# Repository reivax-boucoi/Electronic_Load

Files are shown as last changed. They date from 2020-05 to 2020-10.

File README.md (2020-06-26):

# Electronic Load

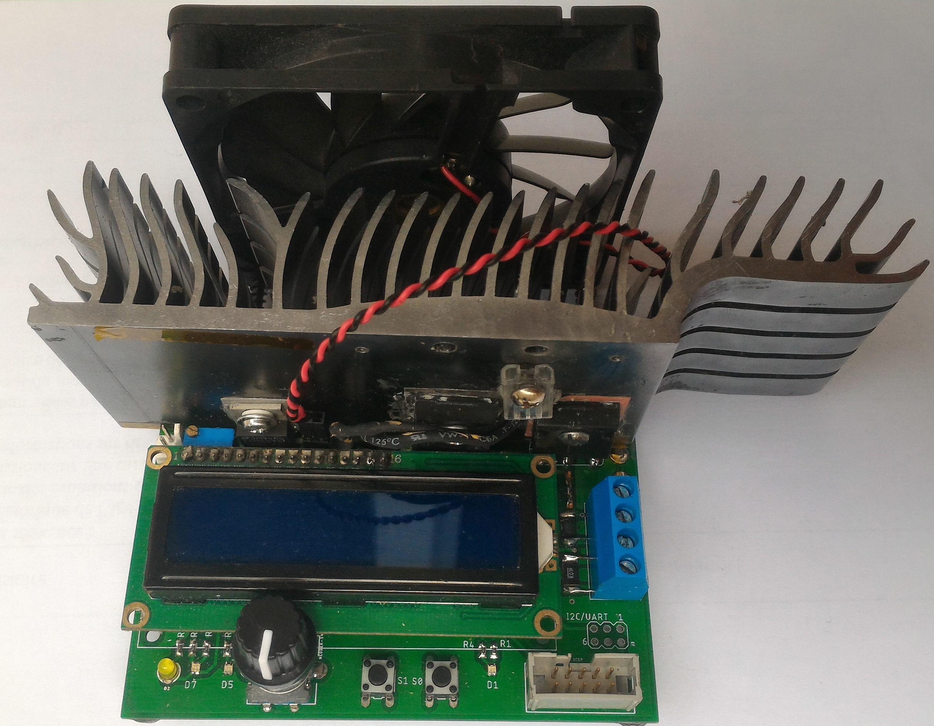
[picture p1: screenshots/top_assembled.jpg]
Image of top assembled


This repository hosts my work in developping a custom electronic load from scratch. 
For more information on what an electronic load does and what it can be used for, see [this](https://www.mouser.com/pdfdocs/DC_Electronic_Load_Application_Note.pdf). 

Specifically, this load targets DC-DC converters testing, as it includes input and output power monitoring.

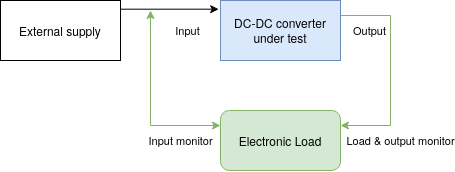
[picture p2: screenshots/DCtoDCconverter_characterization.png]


I you have any question on this repository, feel free to contact the owner at (reivax[dot]boucoi[at]laposte[dot]net).

Featured on [Hackaday](https://hackaday.com/2020/06/06/a-diy-electronic-load-with-a-twist/) and [Electronics-Lab](https://www.electronics-lab.com/diy-electronic-load-dc-dc-converter-characterization/)!

---
---

### Features

* Constant Current, Power and Resistance modes
* Battery capacity logging with adjustable cutoff voltage
* Input and output power logging : instant efficiency reading for DC-DC converters
* Rotary encoder driven interface
* Dedicated Load ON/OFF button
* Intuitive LCD menu system with editable values
* 12bit current, voltage and power measurements 
* 30W continuous sinking capability, 250W peak
* Temperature controlled fan with auto shutdown.
* Adjustable acquistion rate
* 115200 bauds serial communication through USB with a PC (non-isolated !)

### Specifications
> Enough talk, give us the specs, son !

Altough the device has not been fully qualified through systematic testing, here are the basic specs you can expect. 
* Input voltage range : 0 - 100V DC maximum, 2-80V DC regulating
* Supply voltage range : 0 - 16V maximum, 12V nominal 
* Device current consumption : 50mA nominal (0.6W)
* Load current range : 5mA - 5.25A, in 8mA steps
* Current regulation : 5% +/- 8mA typical @ 8kHz bandwidth
* Transient response : rise time < 20µs/A, overshoot < 2%
* Constant Power/Resistance regulation bandwidth : 10Hz

---
---

## Schematic and Layout
The heart of the system is an Atmel ATmega328P AVR microcontroller with 32kB of Flash and 2k of RAM running at a whopping 16MHz. It interfaces an I2C 12bit DAC (the MCP47FEB21A1) and the LTC2992 dual power monitor chip.

The USB serial interface uses the MCP2221A bridge. The display is a classic 16x2 LCD.

On the analog part, 10mΩ  and 0.2Ω shunt resistors are used, coupled with two W9NK90Z N-ch power MOSFETS. The heatsink was salvaged from an old graphics card. Attached are a 10k NTC and a generic fan (12v @ 200mA, 80mm). Current regulation is achieved through the help of a MCP6H02 opamp, and a carefully designed feedback network which guarantees the specified rise time with little to no overshoot.

The layout was done using the Eagle software (v9.5.2). Gerbers, Eagle project files, top and bottom views are available on the `pcb` folder. PCBs were printed using JLCPCB service.
The schematic is available in a pdf and Eagle `.sch` format as well. A Bill of Materials (BOM) is also available, in plain text and html format, on the `pcb` folder.

Several user-definable bi-color status LEDs are included, such as Load ON/OFF, TX & RX, acquisition blink, as well as a power LED.

An expansion/debug port is provided, with +5V, ground, I2C and UART available.

There are several issues regarding the layout of the PCB, as it is a first version. Improper Kelvin connections to the current sense resistors, or wrong hole size for the power input connector by example. The heatsink originally used is salvaged from old equipement and the footprint may not be relevant to anyone else. Space for rubber feet placement should be included. Also, the LCD is too close to the heatsink, which is impractical during assembly (especially accessing the fan and temp sensor connector).

---
---

## Firmware
The firmware for this device is currently in revision 1.3. It is written for a barebone ATmega328p Atmel microcontroller.

```20014 bytes (65%) of program storage space. Maximum is 30720 bytes.```

```1586 bytes (77%) of dynamic memory, 462 bytes left. Maximum is 2048 bytes.```

As you can see it's not the lightest firmware, mostly due to the use of the `Wire` and `LCD` librairies from Arduino, which are bulky. However, there is still enough room for future improvements. Just keep in mind if you want to improve the project to leave space for local variables allocation.

---

### Programming
An ISP port is provided on the board, making reflashing easy. All you need is an AVR-compatible programmer with the standard 10 pins ICSP header. I used the very good (and very cheap!) [Usbasp](https://www.fischl.de/usbasp/) during developpement. Avrdude can be used to download the pre-compiled binary `main.hex`, or you can compile the project yourself first.
`Avr Fuses settings :(E:FD, H:DE, L:FF)`

To program the chip, execute : `avrdude -p m328p -c usbasp -P usb -U flash:w:firmware/main.hex`

---

### Software structure

* Display related stuff : `Screen.cpp`, `Menu.cpp`
* LTC2992 power monitoring stuff : `PM.cpp`
* DC Load stuff : `Load.cpp`
* Generic io interfacing : `Utils.cpp`, `SimpleRotary.cpp`, `Wire.cpp`, `LCD.cpp`
* Serial command parsing : `SerialCommand.cpp`
* Serial interface : `Interface.cpp`
* Control loop and display update : `main.cpp`

---

### Usage
First apply power to the device through USB (for limited load capacity) or, better, 12V DC on the input power jack (beware of polarity).

The welcome screen pops up with the following menus : 

<img src="screenshots/mainmenu.jpg" alt="Image of mainmenu" width="200" text-align: center/>

* Load allows you to set the load parameters and mode (CC/CP/CR)
* Battery enters the battery capacity mode
* Meter measures input power
* Settings is self explanatory

Turn the rotary encoder to cycle through the menus and screens, and push to enter. At any time use the back button (to the right of the encoder) to get back to the previous menu or exit editing mode. 

Editing a value starts by selecting the value to edit. Press enter on a screen, you should get a flashing square in front of a value. Turn the knob until the desired value is selected. Press enter to edit. The leftmost digit is selected. To change the edited digit, press enter once again. Press back to validate. 

**You will have to restart the load in order for the changes to take effect.** This is done to prevent happy little accidents. To start and stop the load, press the rightmost button. The rightmost blue LED should light up. If the rightmost LED turns red, a fault occured. Faults can happen if :
* The heatsink temperature exceeds the hard temperature stop defined in `Load.h`
* The load fails to regulate. This will mostly be caused by the DUT hiccuping (or sharp V/I curve), or insufficent power to the Electronic Load.

The load menu has 4 screens : 

<img src="screenshots/screen_cc.jpg" alt="Image of ccscreen" width="200" text-align: center/><img src="screenshots/screen_cp.jpg" alt="Image of cpscreen" width="200" text-align: center/><img src="screenshots/screen_cr.jpg" alt="Image of crscreen" width="200" text-align: center/><img src="screenshots/screen_eff.jpg" alt="Image of effscreen" width="200" text-align: center/>

The last screen shows the power lost in the DUT (Pr), the efficiency, the input and output voltages of the converter.

The load mode (CC/CP/CR) is determined by the screen displayed when the load is started. If the screen is not one of the CC/CP/CR screens, is starts in the previously used mode.

Here is what the Battery screen looks like :

<img src="screenshots/screen_batt.jpg" alt="Image of battscreen" width="200" text-align: center/>

Set the constant discharge current I and the cutoff voltage Vc before starting the load with the rightmost button. Accumulated capacity in Wh and Ah are displayed. The load will automatically shut off when the input voltage is below the cutoff voltage, and output the capacity values to the serial port. The total capacity will remain displayed until the load is restarted in this mode.

The meter screen shows the input measurements :

<img src="screenshots/screen_meter.jpg" alt="Image of meterscreen" width="200" text-align: center/>

The settings screen alows to modify various parameters : 

<img src="screenshots/screen_settings.jpg" alt="Image of settingsscreen" width="200" text-align: center/>

It monitors the supply voltage and you can change the threshold temperature for the fan, as well as the refresh rate of the screen. Note that the load has a hard temperature stop defined in `Load.h`, and a maximum refresh rate of approx 10Hz.

---

### Serial interface

Several remote operations are available currently, for the load to report data to an external PC. The serial interface provided though USB (115200 bauds) defines the following commands :
- `get [x]` : returns current load data in the format shown below. Once the load is started (manually or with a command), it will take x samples at the acquisition time currently defined and then shut the load down.
- `sweep b e s` : sweeps the current settable value from `b` to `e` in `s` steps. Therefore, current, power or equivalent resistance can be characterized. THis mode is especially useful for efficiency over load characterization. The load is automatically enabled and disabled. Samples are taken after a stabilization time equal to the acquisition time. If the load cannot maintain regulation during the sweep, it will be aborted.
TODO add other commands

Parameters beween brackets are optional.

Example format of response from the load :
TODO here

---
---

## Improvements

- [x] Design a mechanical mount for the fan / stabilize the board
- [x] Re-think the menu system to be more modular / lower size
- [x] Add logging capability with serial interface
- [x] Add current sweep programming for DC-DC converters automatic characterization (with di/dv auto resolution)
* Cleanup and enhance the serial interface (add change mode command, load on/off) 
* Provide python example for graphing live data
* Fix the minimum current issue (currently min is 5mA)
* Fix the 4 terminal Kelvin connection on the 10mΩ current sense resistors in the PCB layout
* Design a usb isolator companion board or add SD card logging addon on i2c bus.
* Design 4.5V->12V boost addon to allow full operation from usb power (check usb power requirements before !)
* Better code commenting
* Save last used confguration on EEPROM for next power-up (is this really needed ?).
* ...

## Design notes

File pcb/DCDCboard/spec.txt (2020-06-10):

Input :

Voltage = 4.8V			USB (before diode so to not backfeed)

=> implies to step down for system power with linear reg (inefficient)

Current = 

Output :

Voltage = 12V nom +-.3V ripple max
Current = ~0.3A 		system + fan(beware of turn on current)

Calculation :

Pout = 12*.3 = 3.6W
Estimated efficiency = 70%
Pin = 3.6/.7 = 5.2W		Is this doable with USB ? What params for MCP2221A to request current ?
Current = 5.2/4.8 = 1.07A	Check with MC34063 max Isw

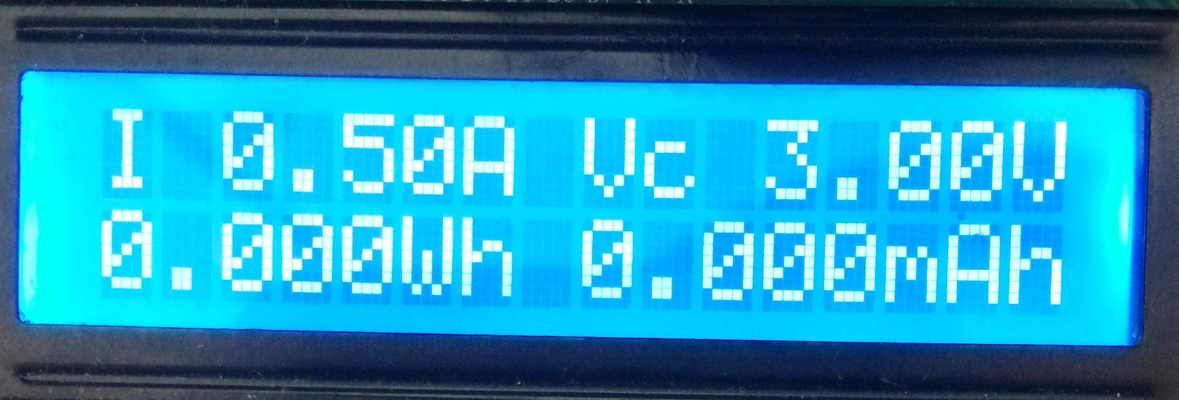
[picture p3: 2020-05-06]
screenshots/screen_batt.jpg

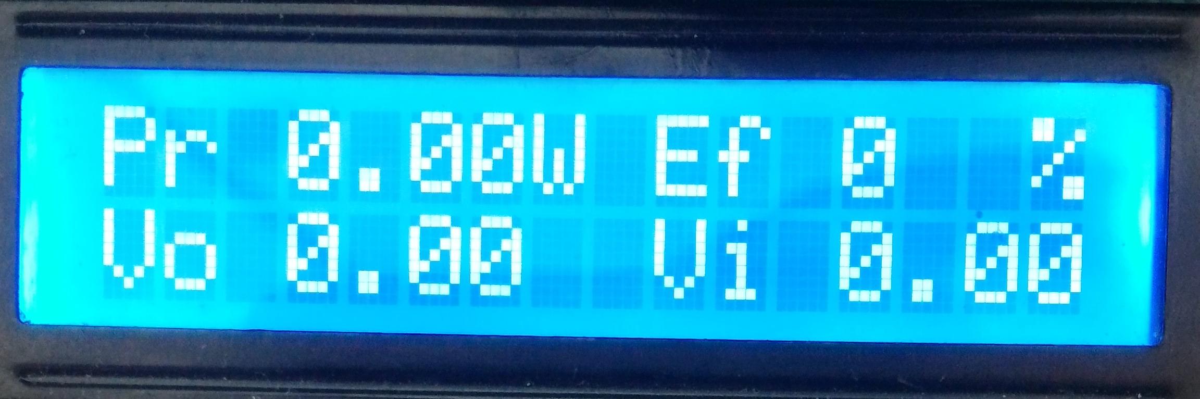
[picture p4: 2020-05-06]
screenshots/screen_eff.jpg

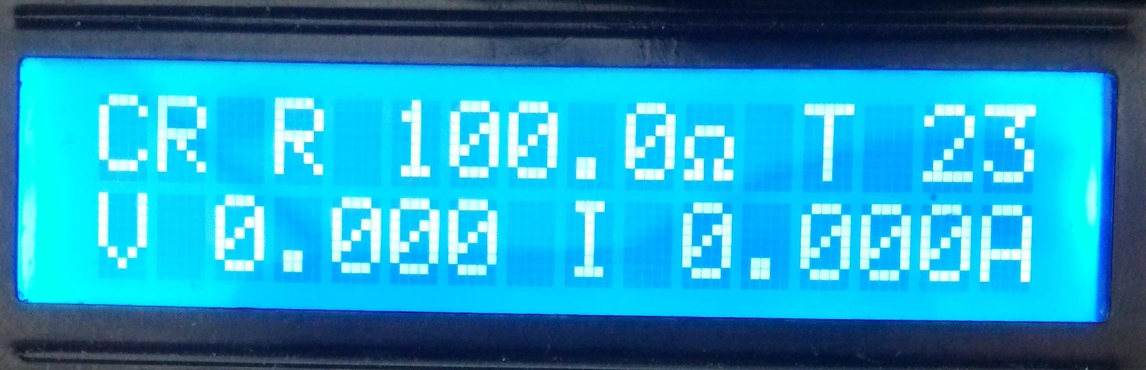
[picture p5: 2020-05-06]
screenshots/screen_cr.jpg

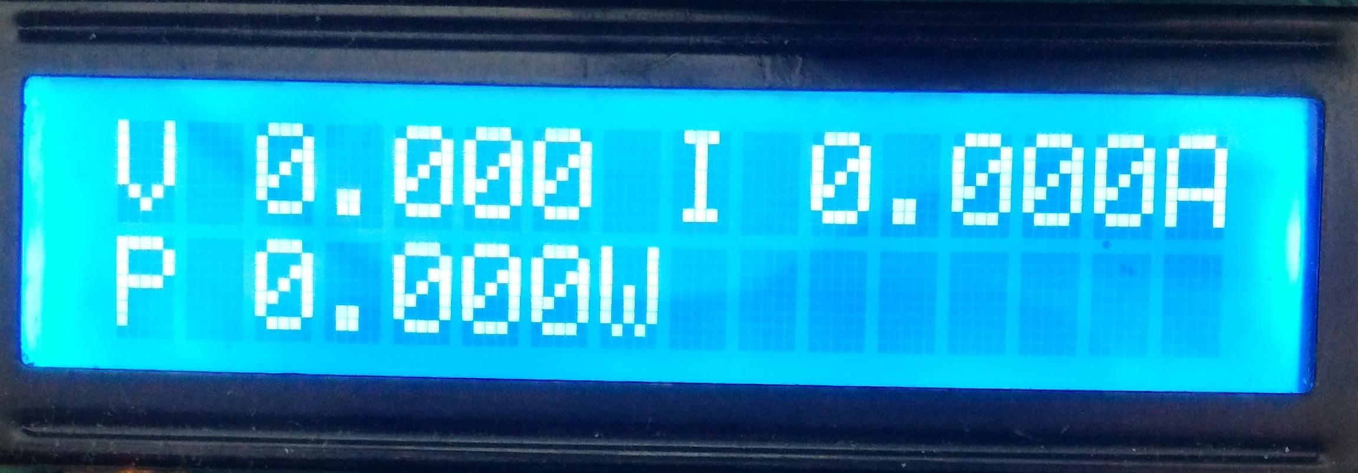
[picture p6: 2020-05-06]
screenshots/screen_meter.jpg

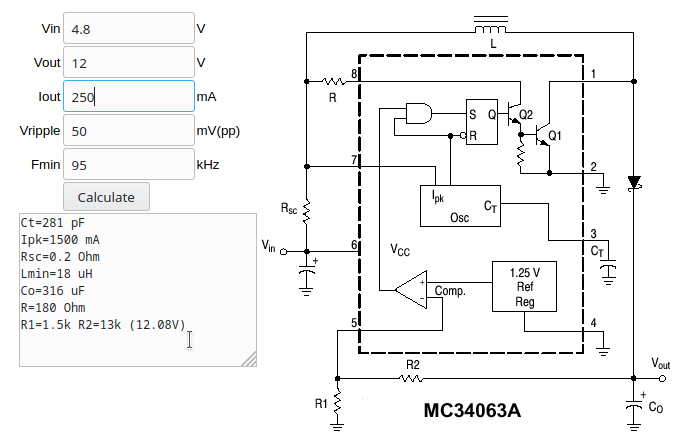
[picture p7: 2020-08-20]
pcb/DCDCboard/dcdc_sch.png

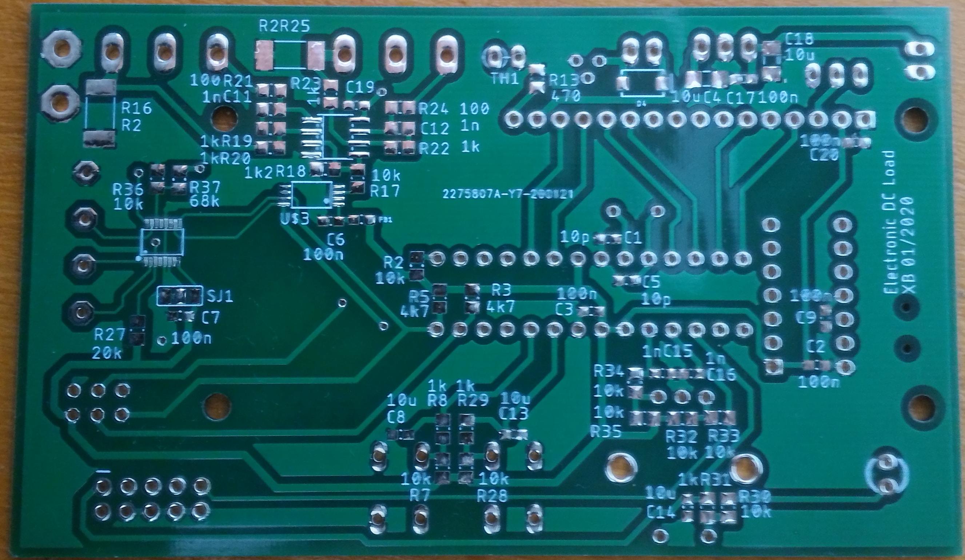
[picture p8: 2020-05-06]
screenshots/bottom_bareboard.jpg

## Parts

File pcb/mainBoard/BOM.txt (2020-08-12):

Qty	Value	Device	Package	Parts	Description	MPN	REF
2	100	R-US_R0805	R0805	"R21, R24"	RESISTOR		
8	100n	C-USC0603	C0603	"C2, C3, C6, C7, C9, C17, C19, C20"	CAPACITOR		
10	10k	R-US_R0805	R0805	"R2, R7, R17, R28, R30, R32, R33, R34, R35, R36"	RESISTOR		
2	10p	C-USC0603	C0603	"C1, C5"	CAPACITOR		
3	10u	C-USC0603	C0603	"C8, C13, C14"	CAPACITOR		
2	10u	C-USC1206	C1206	"C4, C18"	CAPACITOR		
1	16MHz	CRYSTALHC49U70	HC49U70	Q1	CRYSTAL		
2	1A/40V/500mV	DIODE-SCHOTTKY-SS14	SMA-DIODE	"D4, D6"	Schottky diode	DIO-08053	
7	1k	R-US_R0805	R0805	"R8, R19, R20, R22, R23, R29, R31"	RESISTOR		
1	1k2	R-US_R0805	R0805	R18	RESISTOR		
2	1n	C-USC0603	C0603	"C15, C16"	CAPACITOR		
2	1n	C-USC0805	C0805	"C11, C12"	CAPACITOR		
1	20k	R-US_R0805	R0805	R27	RESISTOR		
1	30?/1.8A	FERRITE_BEAD-0603	603	FB1	"Ferrite Bead (blocks, cores, rings, chokes, etc.)"	NDUC-07859	
1	328P	ATMEGA328P_PDIP	DIP28	U1	Atmel 328P	IC-09136	
8	470	R-US_R0805	R0805	"R1, R4, R9, R10, R13, R15, R38, R39"	RESISTOR		
2	4k7	R-US_R0805	R0805	"R3, R5"	RESISTOR		
1	68k	R-US_R0805	R0805	R37	RESISTOR		
1	7805	786TV	TO220V	IC2	Positive VOLTAGE REGULATOR		
1	ADR0	SJ2W	SJ_2	SJ1	SMD solder JUMPER		
3	BICOLOR_LED	BICOLOR_LED	BICOLOR_LED	"D1, D5, D7"	dual 0603 generic		
1	CONTRAST	TRIM_EU-RJ9W	RJ9W	R14	POTENTIOMETER		
1	ENCODER-SWITCH	ENCODER-SWITCH	ROTARY_ENC_PLAIN	S2	Rotary Encoder w/ Select Switch	COM-09117	
1	FAN	PINHD-1X2	1X02	JP2	PIN HEADER		
1	HEATSINK_0NOSILK	HEATSINK_0NOSILK	HEATSINK_01	U$2	Custom heatsink		
1	I2C/UART	MA03-2	MA03-2	SV1	PIN HEADER		
1	ICSP	AVR_SPI_PROG_5X2PTH2	2X5-SHROUDED	J2	AVR 10-pin ICSP Header	CONN-08671	PRT-08506
1	LCD-16X2NOSILK	LCD-16X2NOSILK	LCD-16X2_NOSILK	LCD1	Standard text-only 16x2 parallel input LCD		LCD-00255
1	LTC2992	LTC2992	MSOP16	U$1	Dual supply monitor		
1	MCP2221A	MCP2221A	DIP14	BR1	Usb to uart bridge		
1	MCP47FEB21	MCP47FEB21	TSSOP8	U$3	Dac		
1	MCP602SN	MCP602SN	SO08	IC1	Single Op Amp 2.7V to 6.0V Single Supply CMOS		
1	PWR	PINHD-1X2	1X02	JP1	PIN HEADER		
2	R01	R-US_R2512	R2512	"R11, R12"	RES 0.01 OHM 1% 1W 2512	TL3AR01F	
2	R2	R-US_R2512	R2512	"R16, R25"	RES 0.2 OHM 1% 2W 2512	RLP73K3AR20FTDF	
1		SCREWTERM_5MM_4WAY		X1			
2	STW9NK90Z	STW9NK90Z	TO247BV	"U$4, U$5"			
1	"THERMISTOR-2,5"	"THERMISTOR-2,5"	"RS-2,5"	TH1	THERMISTOR		
1	USB_MINI-B_SMT	USB_MINI-B_SMT	USB-MINIB	J1	USB type Mini-B Connector	CONN-08193	PRT-00587
1	VN2210	VN2210	TO92	U$6			
1	YELLOW	LED3MM	LED_3MM	D2	LED (Generic)	DIO-08794	
2	buttton	10-XX	B3F-10XX	"S0, S1"	OMRON SWITCH	B3F-1000	176432

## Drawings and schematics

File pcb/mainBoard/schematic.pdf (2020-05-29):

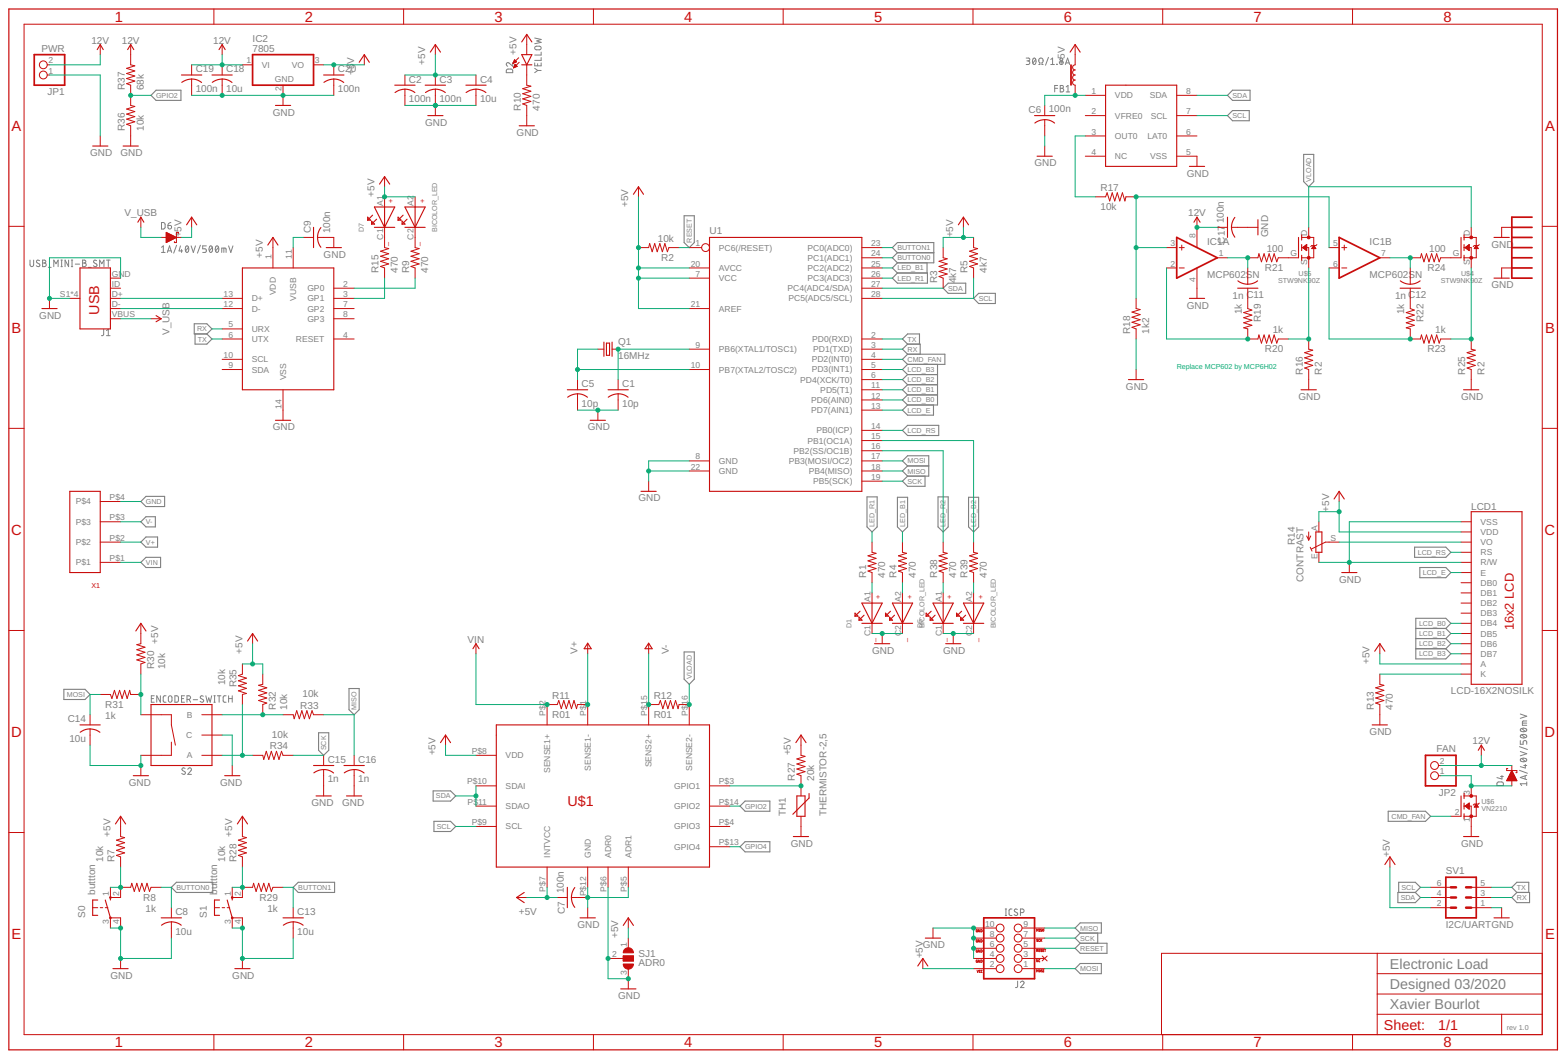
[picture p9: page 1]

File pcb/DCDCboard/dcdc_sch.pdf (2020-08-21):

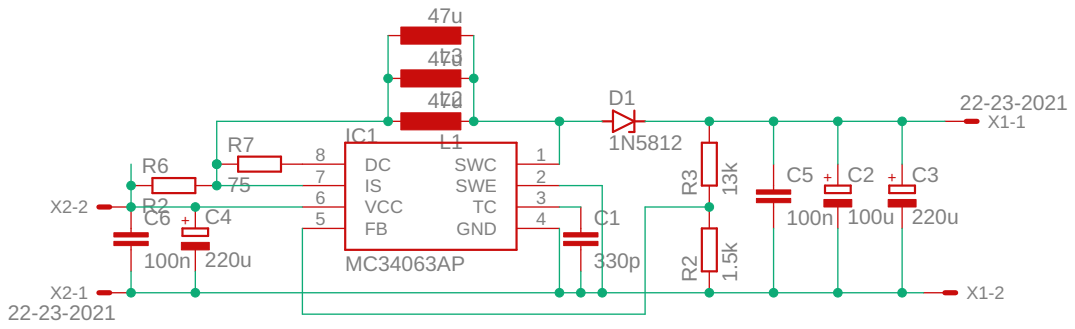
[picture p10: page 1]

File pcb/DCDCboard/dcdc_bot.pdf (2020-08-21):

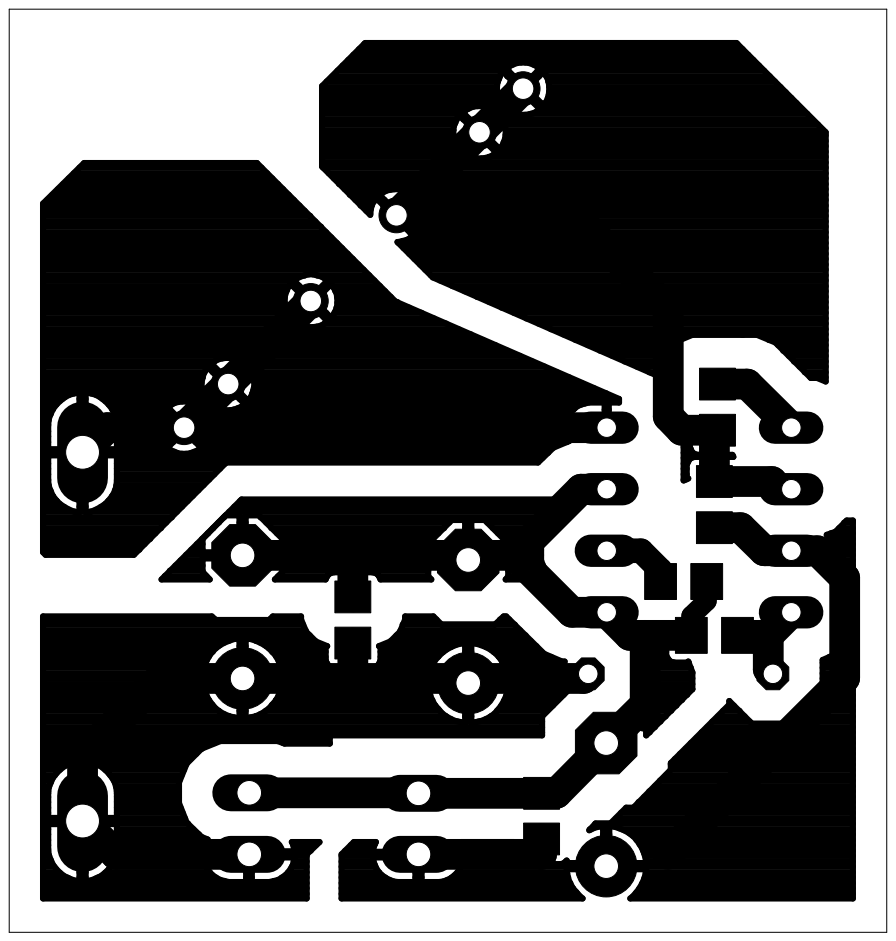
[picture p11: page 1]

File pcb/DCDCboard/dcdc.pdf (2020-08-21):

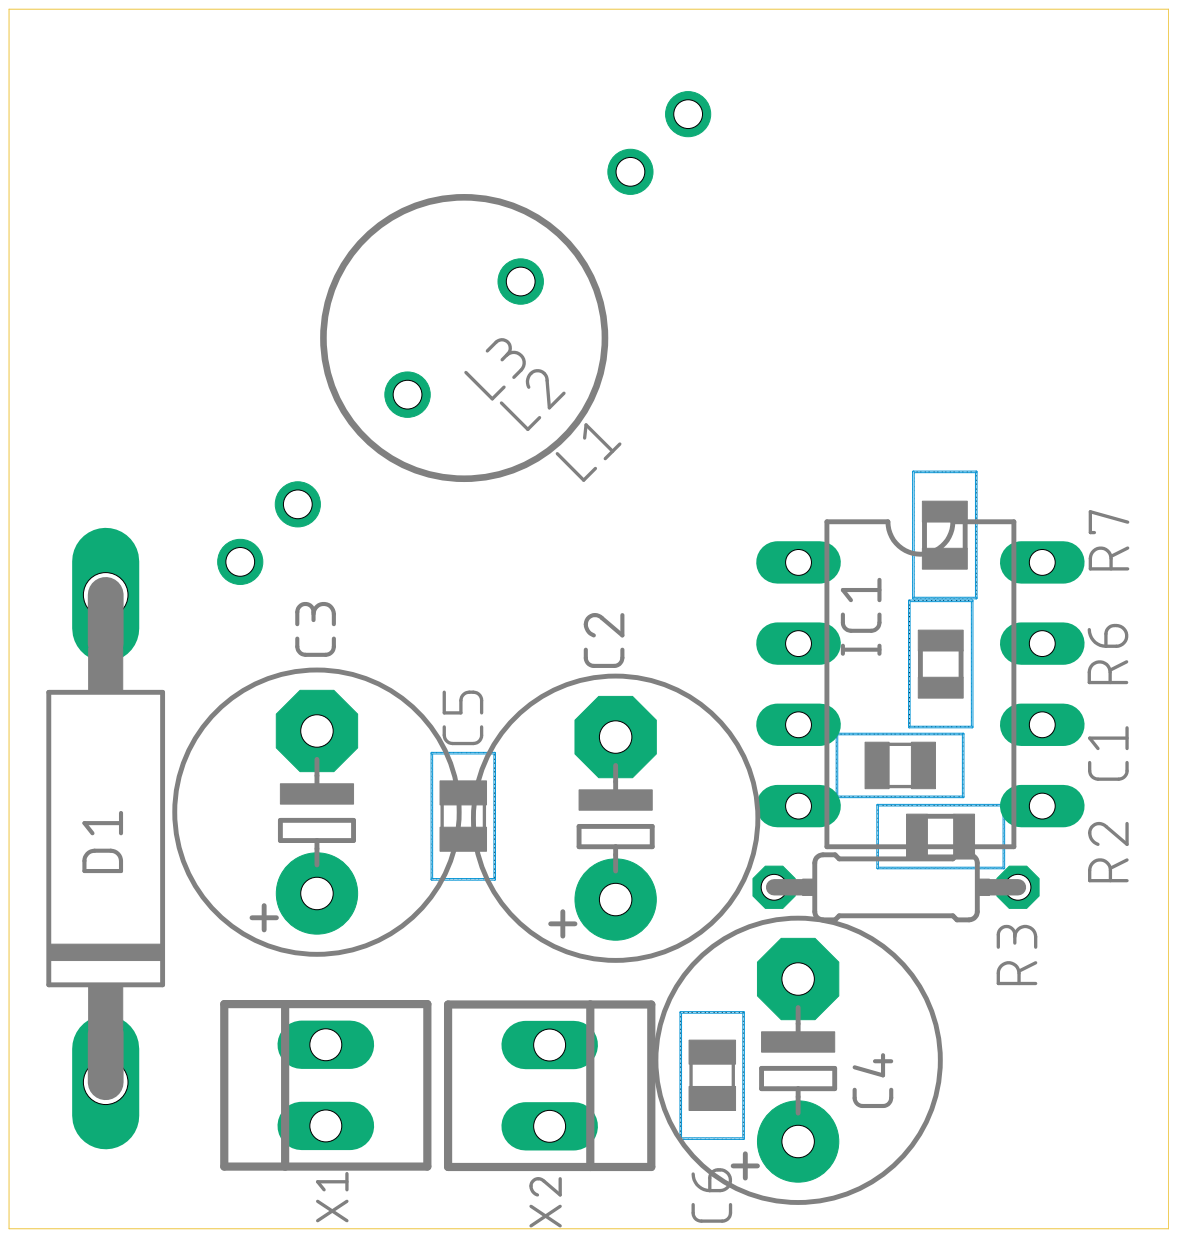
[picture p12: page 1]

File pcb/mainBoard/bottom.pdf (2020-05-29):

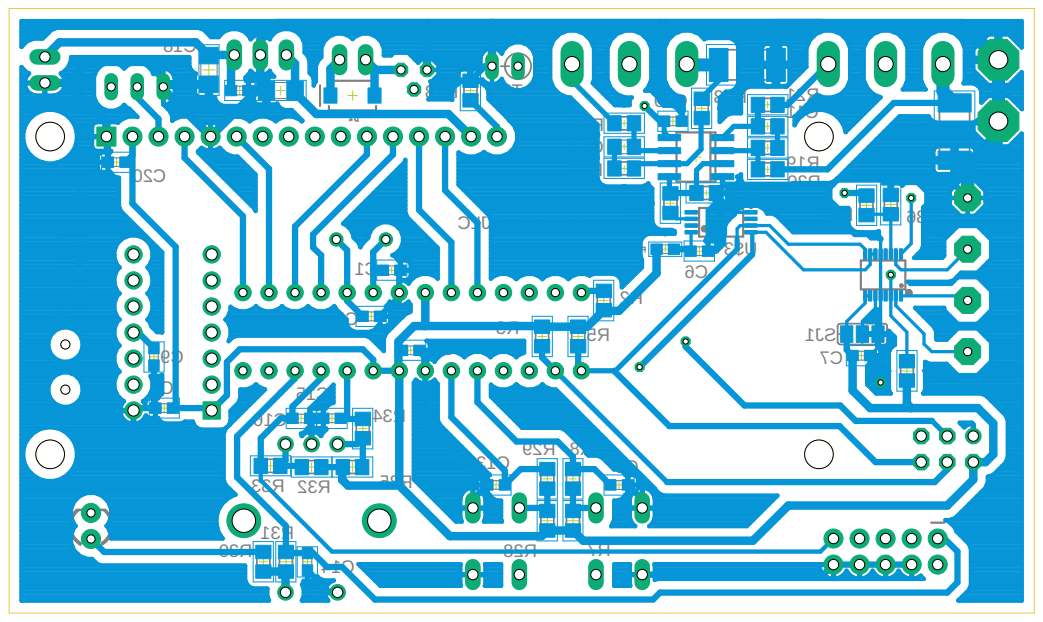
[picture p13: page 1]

Electronic DC Load XB 01/2020

CLJ CLJ CLJ CLJ 73 R 63 R

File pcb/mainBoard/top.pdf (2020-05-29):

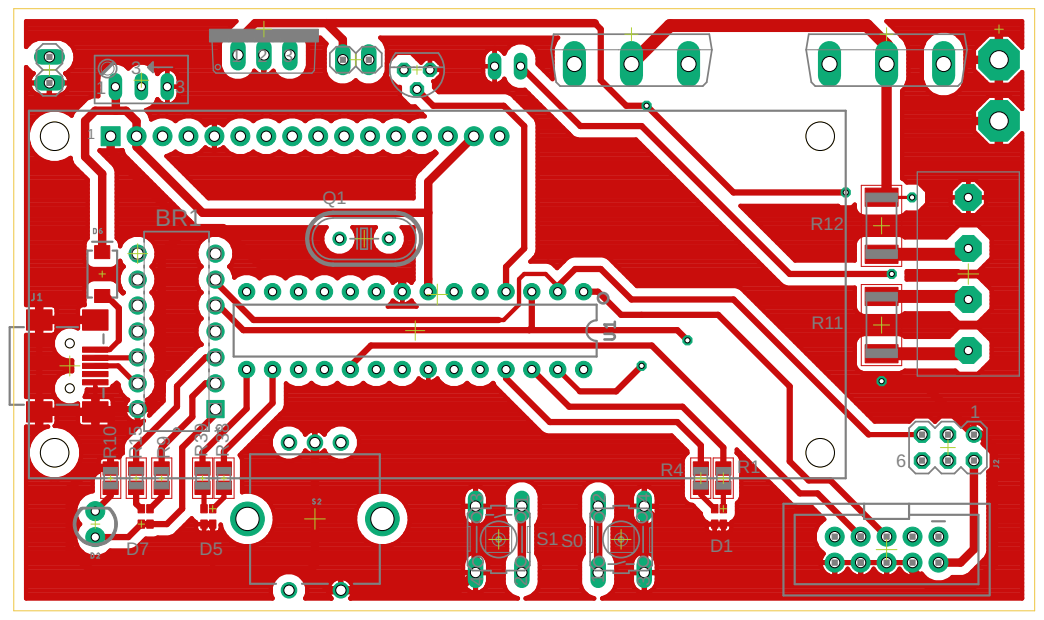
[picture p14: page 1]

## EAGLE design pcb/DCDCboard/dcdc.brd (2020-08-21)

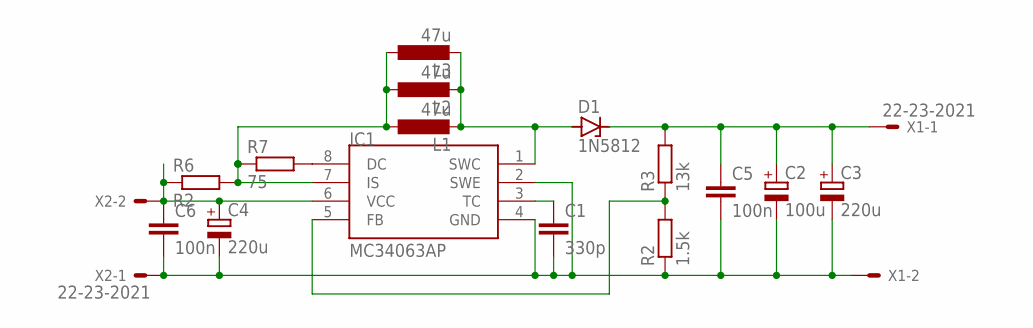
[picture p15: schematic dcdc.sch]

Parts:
C1: 330p; C0805
C2: 100u; E5-8,5
C3, C4: 220u; E5-8,5
C5, C6: 100n; C0805
D1: 1N5812; C1702-15
IC1: MC34063AP; DIL08
L1: 47u; TJ3-U2
L2: 47u; TJ4-U2
L3: 47u; 6000-XXXX-RC
R2: 1.5k; R0805
R3: 13k; 0204/7
R6: R2; R0805
R7: 75; R0805
X1, X2: 22-23-2021

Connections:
FB: IC1.5 (FB), R2.2, R3.1
GND: C1.2, C2.-, C3.-, C4.-, C5.2, C6.2, IC1.2 (SWE), IC1.4 (GND), R2.1, X1.2, X2.1
unnamed: IC1.8 (DC), R7.2
unnamed: IC1.7 (IS), L1.1, L2.1, L3.1, R6.2, R7.1
unnamed: C1.1, IC1.3 (TC)
SW: D1.A, IC1.1 (SWC), L1.2, L2.2, L3.2
VIN: C4.+, C6.1, IC1.6 (VCC), R6.1, X2.2
VOUT: C2.+, C3.+, C5.1, D1.C, R3.2, X1.1

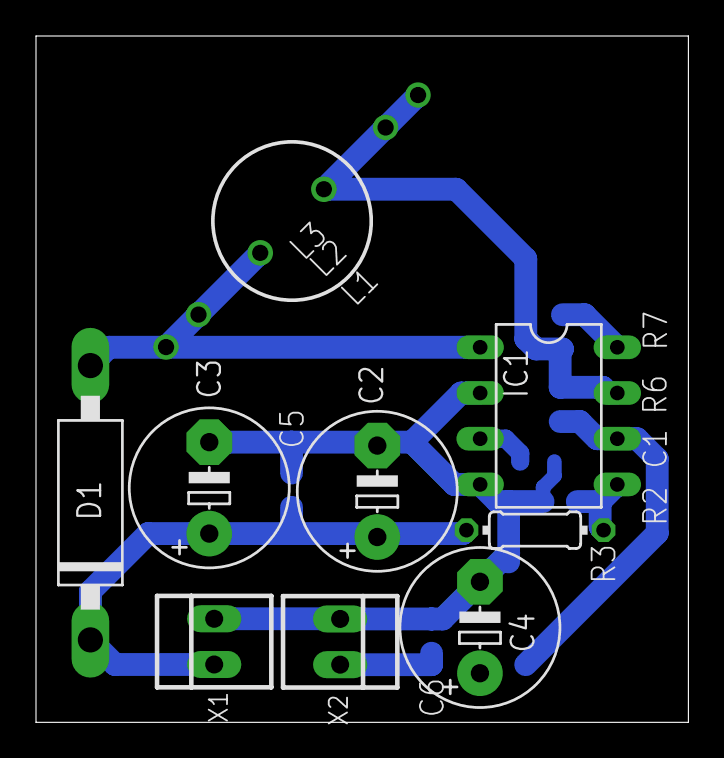
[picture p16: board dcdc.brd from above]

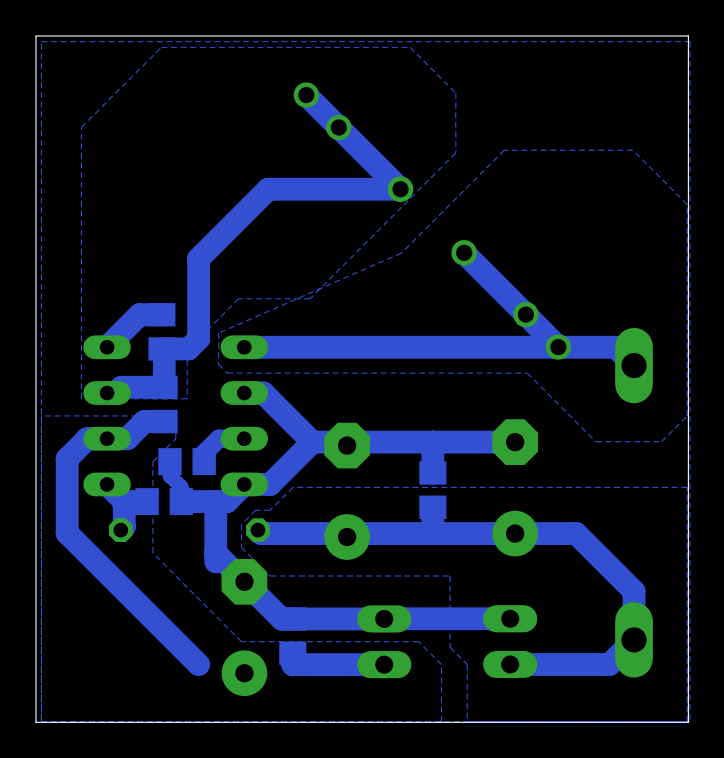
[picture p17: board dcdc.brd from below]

Board: 2 copper layers, 36.2 x 38.1 mm, 17 parts (6 on the bottom side), 8 nets.

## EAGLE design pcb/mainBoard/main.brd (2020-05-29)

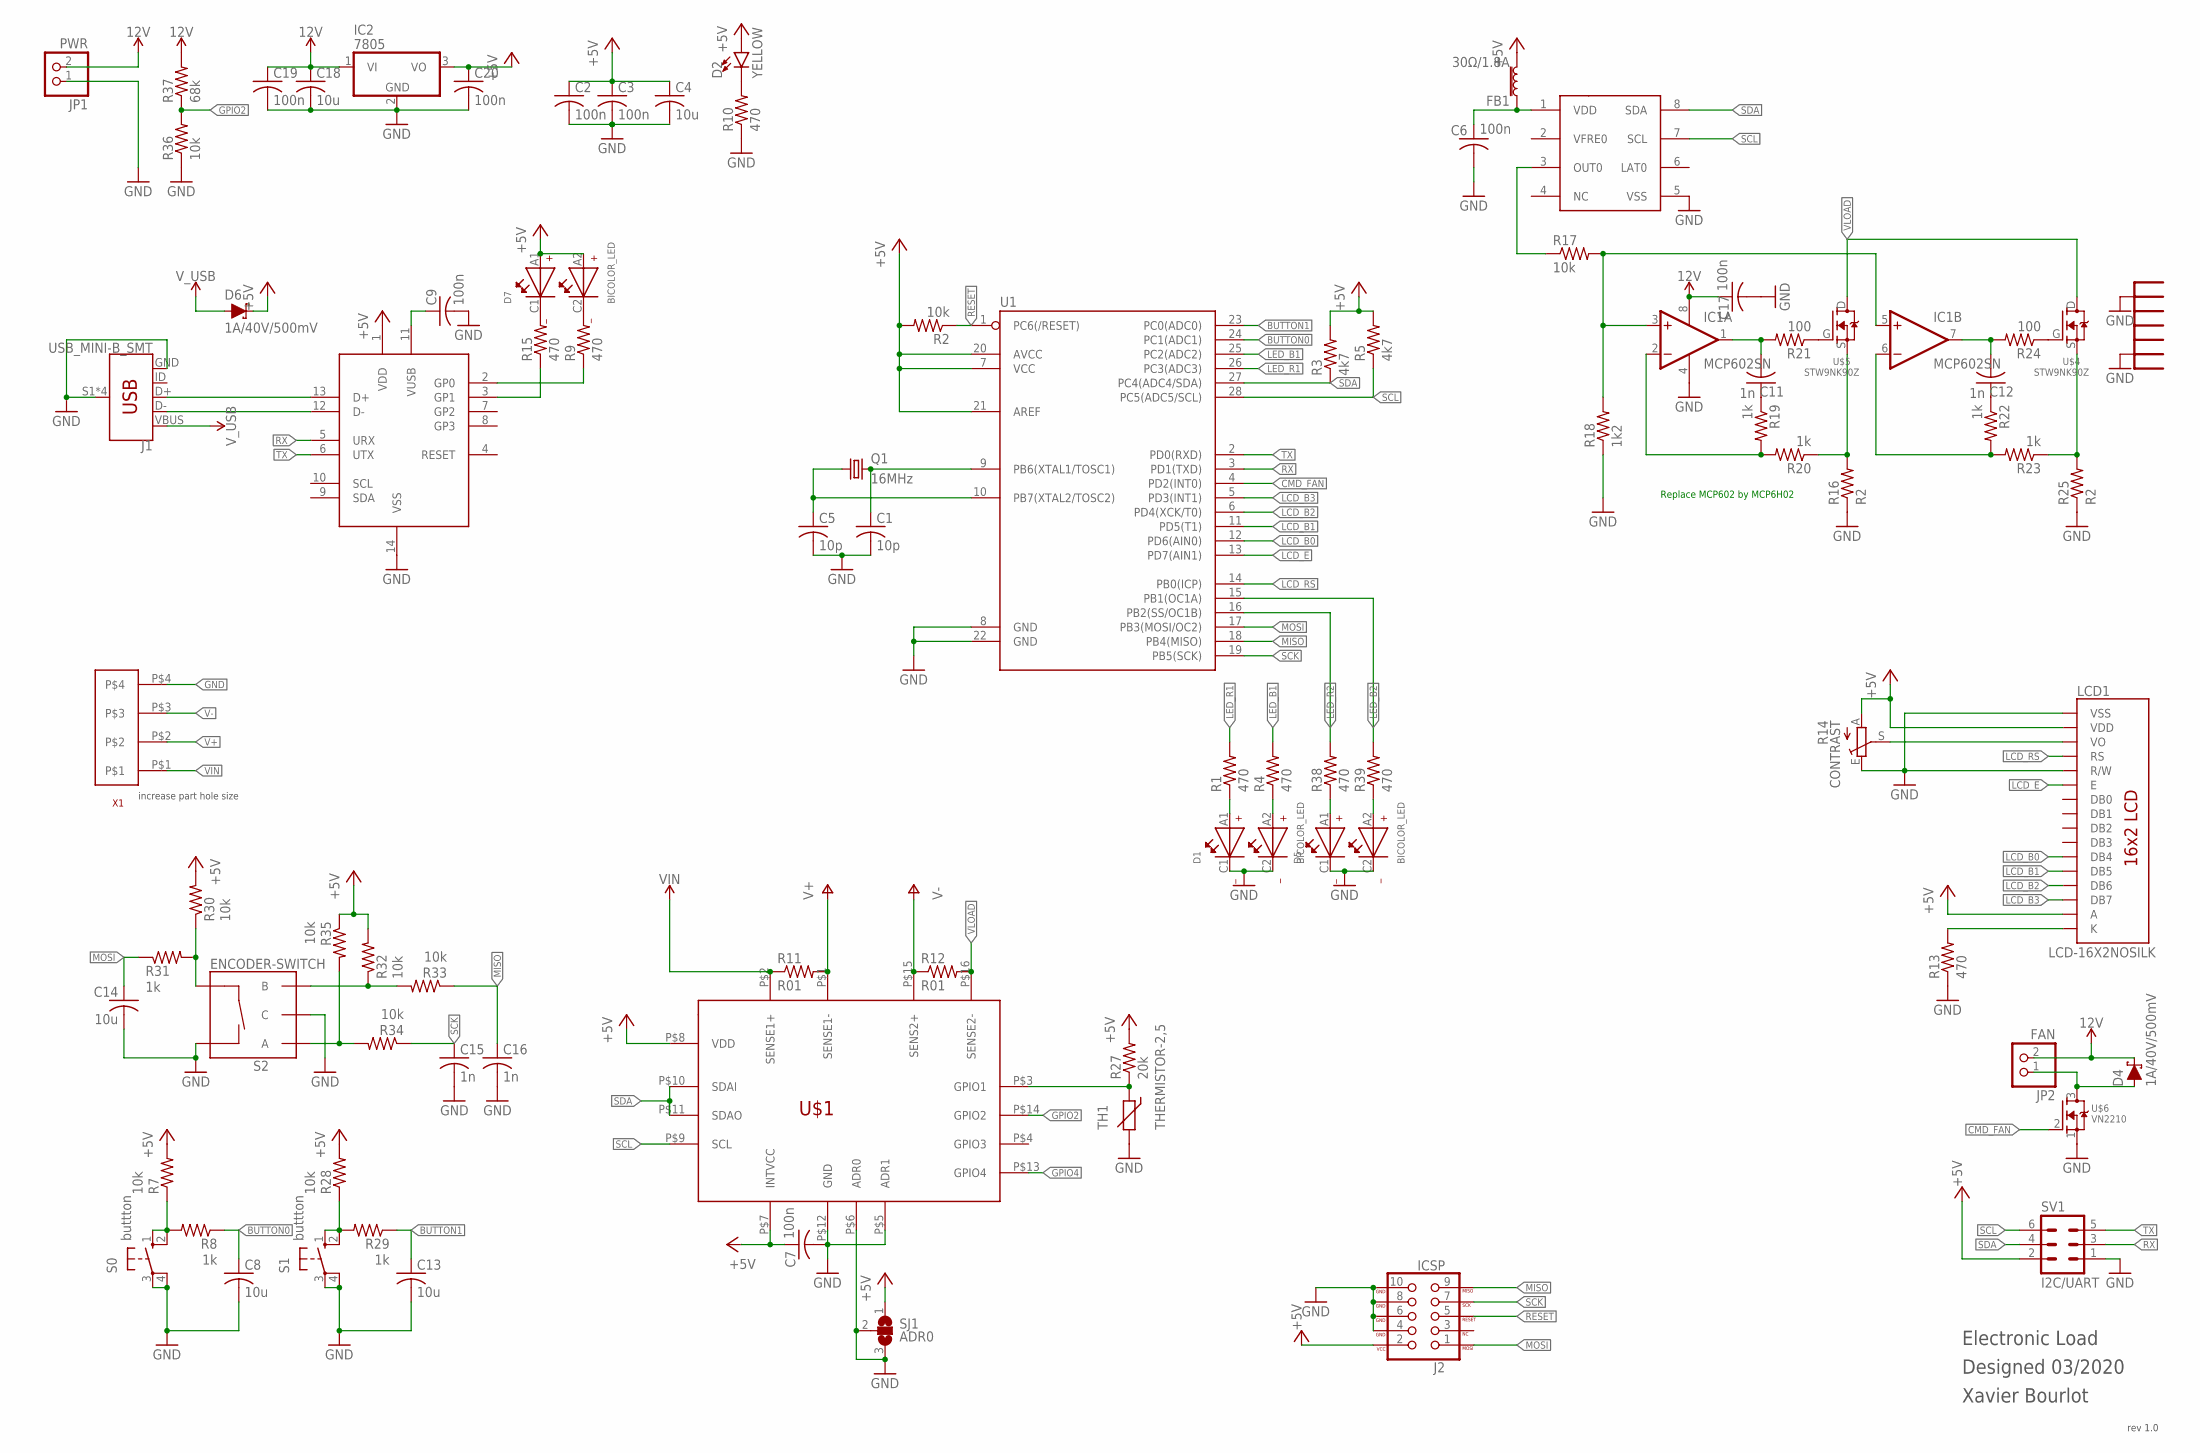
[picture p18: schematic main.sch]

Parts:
BR1: MCP2221A; DIP14
C1, C5: 10p; C0603
C2, C3, C6, C7, C9, C17, C19, C20: 100n; C0603
C4, C18: 10u; C1206
C8, C13, C14: 10u; C0603
C11, C12: 1n; C0805
C15, C16: 1n; C0603
D1, D5, D7: BICOLOR_LED
D2: YELLOW; LED_3MM
D4, D6: 1A/40V/500mV; SMA-DIODE
FB1: 30Ω/1.8A; 0603
IC1: MCP602SN; SO08
IC2: 7805; TO220V
J1: USB_MINI-B_SMT; USB-MINIB
J2: ICSP; 2X5-SHROUDED
JP1: PWR; 1X02
JP2: FAN; 1X02
LCD1: LCD-16X2NOSILK; LCD-16X2_NOSILK
Q1: 16MHz; HC49U70
R1, R4, R9, R10, R13, R15, R38, R39: 470; R0805
R2, R7, R17, R28, R30, R32, R33, R34, R35, R36: 10k; R0805
R3, R5: 4k7; R0805
R8, R19, R20, R22, R23, R29, R31: 1k; R0805
R11, R12: R01; R2512
R14: CONTRAST; RJ9W
R16, R25: R2; R2512
R18: 1k2; R0805
R21, R24: 100; R0805
R27: 20k; R0805
R37: 68k; R0805
S0, S1: buttton; B3F-10XX
S2: ENCODER-SWITCH; ROTARY_ENC_PLAIN
SJ1: ADR0; SJ_2
SV1: I2C/UART; MA03-2
TH1: THERMISTOR-2,5; RS-2,5
U1: 328P; DIP28
U$1: LTC2992; MSOP16
U$2: HEATSINK_0NOSILK; HEATSINK_01
U$3: MCP47FEB21; TSSOP8
U$4, U$5: STW9NK90Z; TO247BV
U$6: VN2210; TO92
X1: SCREWTERM_5MM_4WAY

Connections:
12V: C17.1, C18.1, C19.1, D4.C, IC1.8 (V+), IC2.1 (VI), JP1.2, JP2.2, R37.2
+5V: BR1.1 (VDD), C2.1, C3.1, C4.1, C7.1, C20.1, D2.A, D6.C, D7.A1, D7.A2, FB1.2, IC2.3 (VO), J2.2 (VCC), LCD1.2 (VDD), LCD1.15 (A), R2.2, R3.2, R5.2, R7.2, R14.A, R27.2, R28.2, R30.2, R32.2, R35.1, SJ1.1, SV1.2, U1.7 (VCC), U1.20 (AVCC), U1.21 (AREF), U$1.P$7 (INTVCC), U$1.P$8 (VDD)
B0: R7.1, R8.2, S0.1 (S), S0.2 (S1)
B1: R28.1, R29.2, S1.1 (S), S1.2 (S1)
BUTTON0: C8.1, R8.1, U1.24 (PC1(ADC1))
BUTTON1: C13.1, R29.1, U1.23 (PC0(ADC0))
CMD_FAN: U1.4 (PD2(INT0)), U$6.2 (G)
D+: BR1.13 (D+), J1.D+
D-: BR1.12 (D-), J1.D-
DAC_OUT: R17.1, U$3.3 (OUT0)
FANNEG: D4.A, JP2.1, U$6.3 (D)
GND: BR1.14 (VSS), C1.2, C2.2, C3.2, C4.2, C5.2, C6.2, C7.2, C8.2, C9.2, C13.2, C14.2, C15.2, C16.2, C17.2, C18.2, C19.2, C20.2, D1.C1, D1.C2, D5.C1, D5.C2, IC1.4 (V-), IC2.2 (GND), J1.GND, J1.S1 (SHIELD), J1.S2 (SHIELD), J1.S3 (SHIELD), J1.S4 (SHIELD), J2.4 (GND), J2.6 (GND), J2.8 (GND), J2.10 (GND), JP1.1, LCD1.1 (VSS), LCD1.5 (R/W), R10.1, R13.1, R14.E, R16.1, R18.1, R25.1, R36.1, S0.3, S0.4 (P1), S1.3, S1.4 (P1), S2.C, S2.SW-, SJ1.2, SJ1.3, SV1.1, TH1.2, U1.8 (GND), U1.22 (GND), U$1.P$5 (ADR1), U$1.P$6 (ADR0), U$1.P$12 (GND), U$2.P$1, U$2.P$2, U$3.5 (VSS), U$6.1 (S), X1.P$4
GPIO2: R36.2, R37.1, U$1.P$14 (GPIO2)
GPIO4: U$1.P$13 (GPIO4)
LCD1_CONTRAST: LCD1.3 (VO), R14.S
LCD1_K: LCD1.16 (K), R13.2
LCD_B0: LCD1.11 (DB4), U1.12 (PD6(AIN0))
LCD_B1: LCD1.12 (DB5), U1.11 (PD5(T1))
LCD_B2: LCD1.13 (DB6), U1.6 (PD4(XCK/T0))
LCD_B3: LCD1.14 (DB7), U1.5 (PD3(INT1))
LCD_E: LCD1.6 (E), U1.13 (PD7(AIN1))
LCD_RS: LCD1.4 (RS), U1.14 (PB0(ICP))
LED_B1: R4.2, U1.25 (PC2(ADC2))
LED_B2: R39.2, U1.15 (PB1(OC1A))
LED_R1: R1.2, U1.26 (PC3(ADC3))
LED_R2: R38.2, U1.16 (PB2(SS/OC1B))
MISO: C16.1, J2.9 (MISO), R33.1, U1.18 (PB4(MISO))
MOSI: C14.1, J2.1 (MOSI), R31.1, U1.17 (PB3(MOSI/OC2))
unnamed: C1.1, Q1.2, U1.9 (PB6(XTAL1/TOSC1))
unnamed: C5.1, Q1.1, U1.10 (PB7(XTAL2/TOSC2))
unnamed: C6.1, FB1.1, U$3.1 (VDD)
unnamed: D5.A1, R38.1
unnamed: D5.A2, R39.1
unnamed: D1.A1, R1.1
unnamed: R21.1, U$5.G
unnamed: D1.A2, R4.1
unnamed: BR1.2 (GP0), R9.1
unnamed: BR1.11 (VUSB), C9.1
unnamed: BR1.3 (GP1), R15.1
unnamed: D7.C1, R15.2
unnamed: D7.C2, R9.2
unnamed: D2.K (C), R10.2
unnamed: C11.1, R19.1
unnamed: C12.1, R22.1
RESET: J2.5 (RESET), R2.1, U1.1 (PC6(/RESET))
RX: BR1.5 (URX), SV1.3, U1.3 (PD1(TXD))
SCK: C15.1, J2.7 (SCK), R34.1, U1.19 (PB5(SCK))
SCL: R5.1, SV1.6, U1.28 (PC5(ADC5/SCL)), U$1.P$9 (SCL), U$3.7 (SCL)
SDA: R3.1, SV1.4, U1.27 (PC4(ADC4/SDA)), U$1.P$10 (SDAI), U$1.P$11 (SDAO), U$3.8 (SDA)
TX: BR1.6 (UTX), SV1.5, U1.2 (PD0(RXD))
V+: R11.2, U$1.P$1 (SENSE1-), X1.P$2
V-: R12.1, U$1.P$15 (SENS2+), X1.P$3
VCTRL: IC1.3 (+IN), IC1.5 (+IN), R17.2, R18.2
VENC: R30.1, R31.2, S2.SW+
VENCA: R34.2, R35.2, S2.A
VENCB: R32.1, R33.2, S2.B
VFB1: IC1.2 (-IN), R19.2, R20.2
VFB2: IC1.6 (-IN), R22.2, R23.2
VG2: R24.1, U$4.G
VIN: R11.1, U$1.P$2 (SENSE1+), X1.P$1
VLOAD: R12.2, U$1.P$16 (SENSE2-), U$4.D, U$5.D
VO1: C11.2, IC1.1 (OUT), R21.2
VO2: C12.2, IC1.7 (OUT), R24.2
VS1: R16.2, R20.1, U$5.S
VS2: R23.1, R25.2, U$4.S
VT: R27.1, TH1.1, U$1.P$3 (GPIO1)
V_USB: D6.A, J1.VBUS

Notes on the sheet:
Replace MCP602 by MCP6H02
Electronic Load
Designed 03/2020
Xavier Bourlot
rev 1.0
increase part hole size

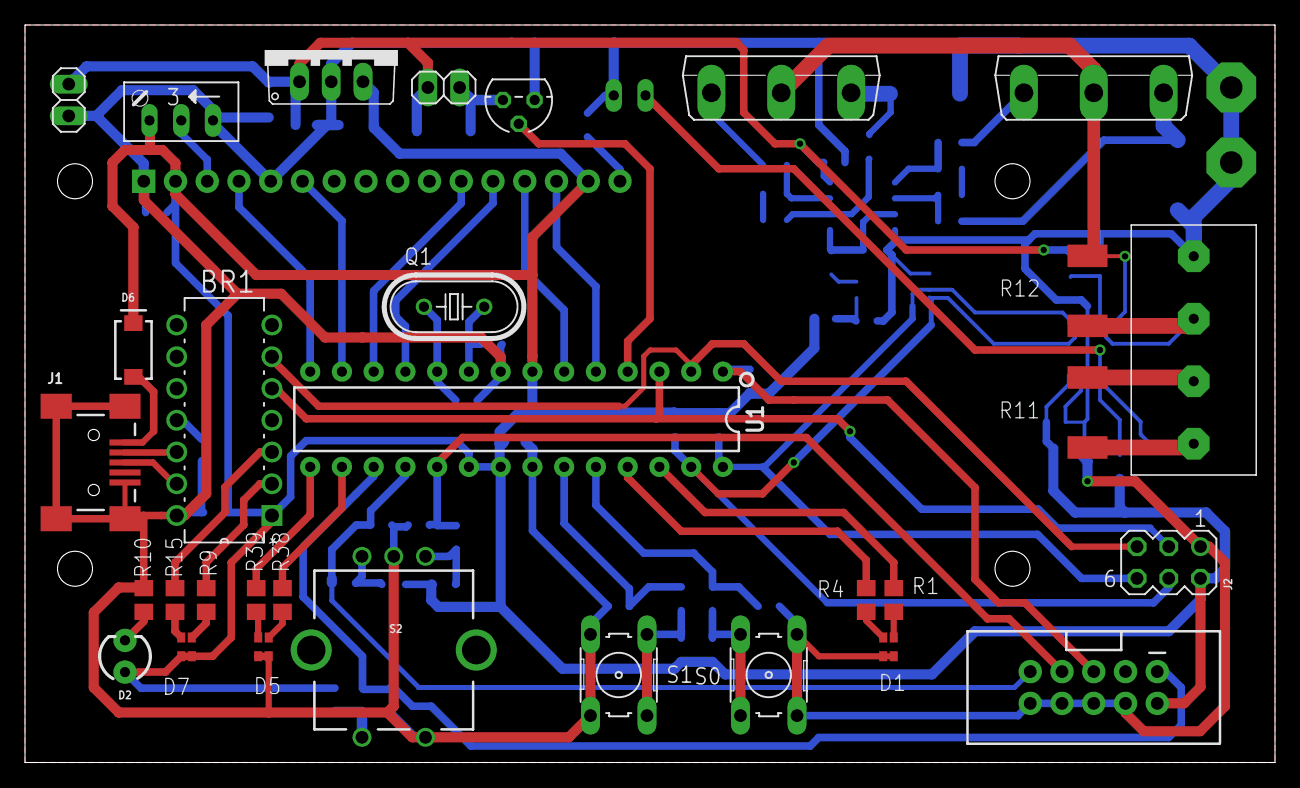
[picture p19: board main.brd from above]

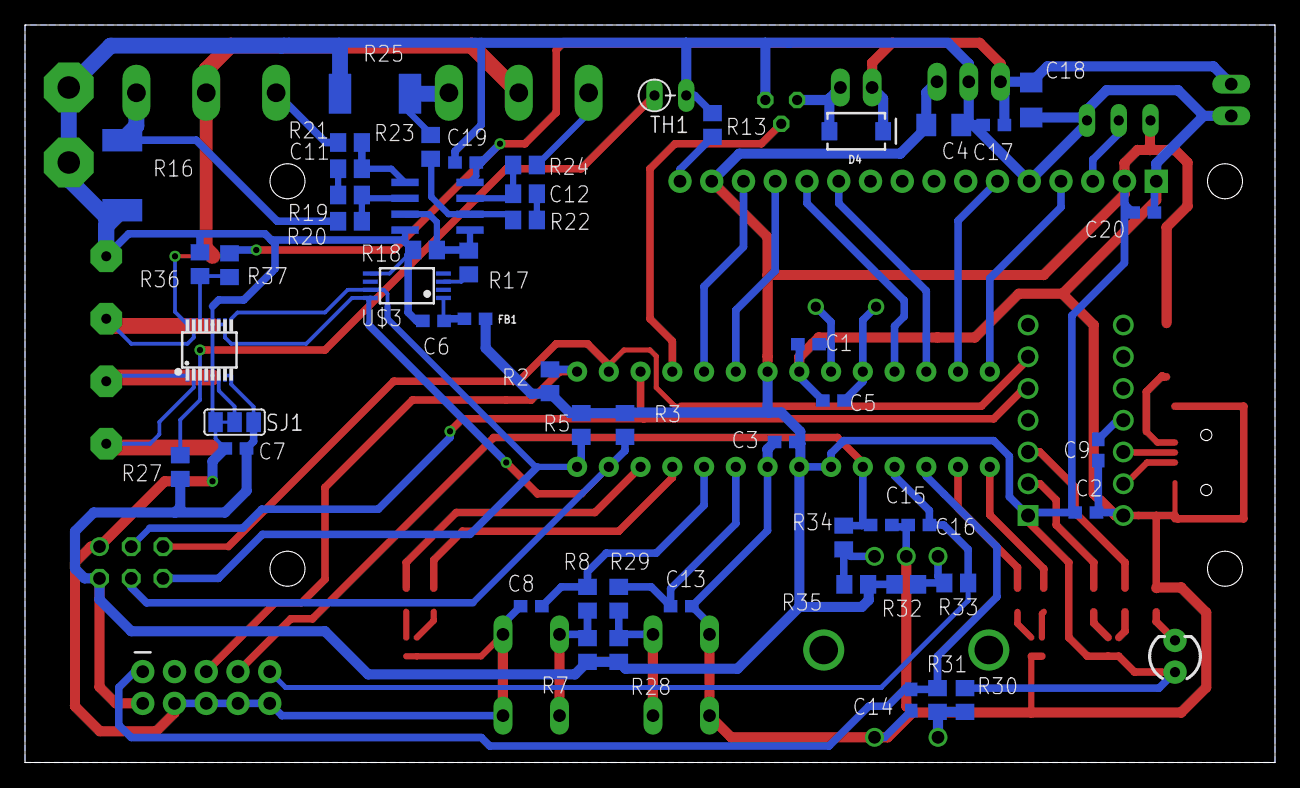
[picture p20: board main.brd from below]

Board: 2 copper layers, 100.0 x 59.0 mm, 86 parts (53 on the bottom side), 66 nets.

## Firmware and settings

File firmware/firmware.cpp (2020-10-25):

#include <avr/pgmspace.h>
#include <LiquidCrystal.h>
#include <SimpleRotary.h>
#include <Wire.h>
#include "Screen.h"
#include "Menu.h"
#include "Load.h"
#include "PM.h"
#include "SerialCommand.h"




#define VERSION_NUMBER "1.3"

#define BTN_BACK_PIN A0
#define BTN_LOAD_PIN A1
#define ENC_A_PIN 12
#define ENC_B_PIN 13
#define ENC_SW_PIN 11
#define LEDR1_PIN 9
#define LEDB1_PIN 10

#define ACQ_TIME 150.0    //time in ms
#define ACQ_HOUR (ACQ_TIME/(3600.0*1000.0))

#define VOLTAGE_MAX 50.0
#define RSET_MAX 1000.0
#define RSET_MIN 0.2
#define CURRENT_MAX 5.1
#define POWER_MAX   500.0

#define OUTOFREGNB  10
#define OUTOFREGPERCENT 0.1

bool BTN_LOAD_state = true;
bool BTN_BACK_state = true;

void BTN_LOAD_check(void);
void BTN_BACK_check(void);
float calc_iload(void);
void build_menu(void);
void interface_init(void);
void interface_poll(void);

//Rotary encoder : 13 12, btn 11
SimpleRotary rotary(ENC_A_PIN, ENC_B_PIN, ENC_SW_PIN);


const int LCD_RS = 8, LCD_E = 7, LCD_D4 = 6, LCD_D5 = 5, LCD_D6 = 4, LCD_D7 = 3;
LiquidCrystal lcd = LiquidCrystal(8, 7, 6, 5, 4, 3);


PM pm;
Load load;
SerialCommand SCmd;

//meter values
float i_meas = 0;
float v_meas = 0;
float p_meas = 0;

//load input values
float iset_load = .5;
float pset_load = 1;
float rset_load = 100;

enum LoadMode {CP = 1, CC = 0, CR = 2, BATT = 3};
const char*loadName[4] = {"CC", "CP", "CR", "BATT"};
LoadMode loadMode = CC;

//out of regulation error counter
uint8_t outOfReg = 0;

//load output values
float temp = 25.0;
float v_batt = 12.0;
float vdisp_load = 0;
float idisp_load = 0;
float pdisp_load = 0;

//lost power
float p_loss = 0;

float refresh_rate = .5; //acquisition time
float fan_temp = 30.0; //fan temp
float outOfRegOn=1.0; // out of reg enable/disable
float eff = 0;

//battery values
float iset_batt = 0.5;
float vcutoff_batt = 3.0;
float capAh_batt = 0.0;
float capWh_batt = 0.0;

unsigned long time1 = 0;
unsigned long time2 = 0;



Value i_measV(&i_meas, 10, 0, 4);
Value v_measV(&v_meas, 2, 0, 4);
Value p_measV(&p_meas, 2, 1, 4);

Value i_setV(&iset_load, 5, 0, 4, 0.0, CURRENT_MAX);
Value p_setV(&pset_load, 5, 0, 4, 0.0, POWER_MAX);
Value r_setV(&rset_load, 5, 0, 4, RSET_MIN, RSET_MAX);

Value tempV(&temp, 14, 0, 0);
Value tempV1(&temp, 14, 0, 0);
Value tempV2(&temp, 14, 0, 0);
Value v_battV(&v_batt, 5, 0, 3);
Value v_loadV(&vdisp_load, 2, 1, 4);
Value v_loadV1(&vdisp_load, 2, 1, 4);
Value v_loadV2(&vdisp_load, 2, 1, 4);

Value p_loadV(&pdisp_load, 10, 1, 4);
Value i_loadV(&idisp_load, 10, 1, 4);
Value i_loadV1(&idisp_load, 10, 1, 4);

//CE screen
Value pr_loadV(&p_loss, 3, 0, 3);
Value effV(&eff, 12, 0, 0);
Value v_load_eV(&vdisp_load, 3, 1, 3);
Value v_meas_eV(&v_meas, 12, 1, 3);

Value refresh_rateV(&refresh_rate, 5, 1, 2, 0.05, 10);
Value setting2V(&fan_temp, 14, 1, 2, 20, 50);
Value setting3V(&outOfRegOn,15,0,1,0,1);


Value vcutoff_battV(&vcutoff_batt, 11, 0, 3, 0, VOLTAGE_MAX);
Value iset_battV(&iset_batt, 2, 0, 3, 0.0, CURRENT_MAX);
Value capAh_battV(&capAh_batt, 8, 1, 4);
Value capWh_battV(&capWh_batt, 0, 1, 4);


const String myStr = String("CR R      ") + String((char)244) + String(" T   ");		//myStr.c_str()

Screen meterScreen   (&v_measV);
Screen CCloadScreen (&i_setV);
Screen CPloadScreen (&p_setV);
Screen CRloadScreen (&r_setV);
Screen CEloadScreen (&pr_loadV);
Screen settingsScreen (&v_battV);
Screen battScreen (&iset_battV);


MenuItem meterItem(0, 1, &meterScreen);
MenuItem loadItem(0, 0, &CCloadScreen);
MenuItem battItem(7, 0, &battScreen);
MenuItem settingsItem(7, 1, &settingsScreen);

Menu mainMenu(&loadItem);

uint16_t interface_nbSteps = 0;
float interface_stepsize = 0.0;
Value *inteface_varPt = &i_setV;

void setup() {
    Serial.begin(115200);
    Wire.begin();
   // pm.init();
    load.init();
    interface_init();

    pinMode(ENC_A_PIN, INPUT);
    pinMode(ENC_B_PIN, INPUT);
    pinMode(ENC_SW_PIN, INPUT);
    pinMode(BTN_BACK_PIN, INPUT);
    pinMode(BTN_LOAD_PIN, INPUT);
    pinMode(LEDB1_PIN, OUTPUT);
    digitalWrite(LEDB1_PIN, 0);

    lcd.begin(16, 2);
    lcd.print(F("Electronic Load"));
    lcd.setCursor(0, 1);
    lcd.print(F("0-100V 0-5A v"));
    lcd.print(VERSION_NUMBER);
    build_menu();
    Serial.println(F("Electronic Load Started !"));
    delay(1500);

    mainMenu.show();

    time1 = millis();
    time2 = millis();
}


void loop() {

    BTN_LOAD_check();
    BTN_BACK_check();
    byte i;
    i = rotary.rotate();
    if (i == 1) {
        mainMenu.next();
    } else if (i == 2) {
        mainMenu.prev();
    }
    if (rotary.push()) {
        mainMenu.enter();
    }
    
    if (time1 + ACQ_TIME < millis()) {  //occurs @ 10Hz

        //digitalWrite(LEDB1_PIN, HIGH);
       /* if (pm.dataReady()) {
            pm.readInputPower(&v_meas, &i_meas, &p_meas);
            pm.readOutputPower(&vdisp_load, &idisp_load, &pdisp_load);
*/
            load.regulate(calc_iload(), temp);

  /*      } else {
            Serial.println(F("PMACQ not ready !"));
        }
        if (loadMode == BATT && load.onState) { //accumulate in BATT mode
            if (vdisp_load < vcutoff_batt) { //cutoff
                load.off();
                loadMode = CC;
                Serial.print(F("Load cutoff ! Accumulated values : "));
                Serial.print(capAh_batt);
                Serial.print(F("mAh, Wh :"));
                Serial.println(capWh_batt, 3);
            } else {
                capAh_batt += idisp_load * 1000.0 * (ACQ_HOUR);
                capWh_batt += pdisp_load * (ACQ_HOUR);
            }
        }
*/
        //digitalWrite(LEDB1_PIN, LOW);
        time1 = millis();
    } else if (time2 + refresh_rate * 1000 < millis()) { //occurs @ refreshRate(0.5s default)
        digitalWrite(LEDB1_PIN, HIGH);

        /*while (!pm.dataReady());

        //battery supply check
        v_batt = pm.readBatt();
        if (false && v_batt < 7.0) {
            Serial.print(F("Supply Low : "));
            Serial.print(v_batt);
            Serial.println(F("V !"));
        }
        //temperature check
        temp = pm.readTemp();
        //efficiency calculation
        if (p_meas > 0.0)eff = 100.0 * (pdisp_load / p_meas);
        eff = constrain(eff, 0, 99);
        //ploss calculation
        p_loss = p_meas - pdisp_load;
        p_loss = max(0, p_loss);
*/

        mainMenu.refresh();

        if (interface_nbSteps && load.onState) {//wait for the load to be on to take samples
            interface_nbSteps--;
            interface_printLoad(false);
            if (interface_nbSteps == 0) {
                load.off();
            } else {
                if ((*inteface_varPt).change(interface_stepsize)) {
                    interface_nbSteps = 0;
                    load.off();
                    Serial.println(F("Sweep exceeded parameter limits"));
                }
            }
        }

        digitalWrite(LEDB1_PIN, LOW);
        time2 = millis();
    }
    interface_poll();
}

void getLoadModeFromMenu(void) {
    if (mainMenu.entered) {    //update load mode based on current menu. If not a CC/CP/CR/BATT menu keep the last mode
        MenuItem* m = mainMenu.selectedMenuItem;
        if (m->selectedScreen == &CCloadScreen) {
            loadMode = CC;
        } else if (m->selectedScreen == &CPloadScreen) {
            loadMode = CP;
        } else if (m->selectedScreen == &CRloadScreen) {
            loadMode = CR;
        } else if (m == &battItem) {
            loadMode = BATT;
            capAh_batt = 0;
            capWh_batt = 0;
        }
    }
}

void BTN_LOAD_check(void) {
    if (digitalRead(BTN_LOAD_PIN) != BTN_LOAD_state) {
        BTN_LOAD_state = !BTN_LOAD_state;
        if (!BTN_LOAD_state) {
            if (load.onState) {
                load.off();
                //Serial.println(F("Load turned off"));
            } else {
                getLoadModeFromMenu();
                load.on(calc_iload());

               /*   Serial.print(F("Load turned on in "));
                    Serial.print(loadName[loadMode]);
                    Serial.print(F(", current set to "));
                    Serial.println(calc_iload());
                */
            }
        }
    }
}
void BTN_BACK_check(void) {
    if (digitalRead(BTN_BACK_PIN) != BTN_BACK_state) {
        BTN_BACK_state = !BTN_BACK_state;
        if (!BTN_BACK_state) {
            mainMenu.back();
        }
    }
}
float calc_iload(void) {
    float res = 0;
    switch (loadMode) {
        case CC:
            res = iset_load;
            temp=(res>1.0)? 31.0: 27.0;
            break;
        case CP:
            if (vdisp_load > 0.0)res = constrain(pset_load / vdisp_load, 0, CURRENT_MAX);
            break;
        case CR:
            res = constrain(vdisp_load / rset_load, 0, CURRENT_MAX);
            break;
        case BATT:
            res = iset_batt;
            break;
    }

    /*if (load.onState && outOfRegOn>0.5 && ((res * (1.0 + OUTOFREGPERCENT)) < idisp_load || (res * (1.0 - OUTOFREGPERCENT)) > idisp_load) ) {
        //  Serial.println(F("Regulation error detected"));
        if (++outOfReg > OUTOFREGNB) {
            outOfReg = 0;
            load.fault = true;
            Serial.println(F("Regulation can't keep up"));
            interface_nbSteps = 0;
        }
    } else {
        outOfReg = 0;
    }*/
    return res;
}
void build_menu(void) {
    meterScreen.txt1 = F("V       I      A");
    meterScreen.txt2 = F("P      W        ");
    CCloadScreen.txt1 = F("CC I      A T   ");
    CCloadScreen.txt2 = F("V       P      W");
    CPloadScreen.txt1 = F("CP P      W T   ");
    CPloadScreen.txt2 = F("V       I      A");
    CRloadScreen.txt1 = F("CR R      O T   ");
    CRloadScreen.txt2 = F("V       I      A");
    CEloadScreen.txt1 = F("Pr     W Ef    %");
    CEloadScreen.txt2 = F("Vo       Vi     ");
    settingsScreen.txt1 = F("Batt     V Reg  ");
    settingsScreen.txt2 = F("Tacq    s Fan   ");
    battScreen.txt1 = F("I     A Vc     V");
    battScreen.txt2 = F("     Wh      mAh");

    meterItem.name = F("Meter");
    loadItem.name = F("Load");
    battItem.name = F("Battery");
    settingsItem.name = F("Settings");

    meterScreen.addValue(&i_measV);
    meterScreen.addValue(&p_measV);
    CCloadScreen.addValue(&tempV);
    CCloadScreen.addValue(&v_loadV);
    CCloadScreen.addValue(&p_loadV);
    CPloadScreen.addValue(&tempV1);
    CPloadScreen.addValue(&v_loadV1);
    CPloadScreen.addValue(&i_loadV);
    CRloadScreen.addValue(&tempV2);
    CRloadScreen.addValue(&v_loadV2);
    CRloadScreen.addValue(&i_loadV1);
    CEloadScreen.addValue(&effV);
    CEloadScreen.addValue(&v_load_eV);
    CEloadScreen.addValue(&v_meas_eV);
    settingsScreen.addValue(&refresh_rateV);
    settingsScreen.addValue(&setting2V);
    settingsScreen.addValue(&setting3V);
    battScreen.addValue(&vcutoff_battV);
    battScreen.addValue(&capWh_battV);
    battScreen.addValue(&capAh_battV);

    loadItem.addScreen(&CEloadScreen);
    loadItem.addScreen(&CRloadScreen);
    loadItem.addScreen(&CPloadScreen);

    mainMenu.addMenuItem(&settingsItem);
    mainMenu.addMenuItem(&meterItem);
    mainMenu.addMenuItem(&battItem);
}
void interface_printLoad(bool header) {
    if (header) {
        Serial.println(F("Mode\tI(mA)\tV\tP(mW)\tIin(mA)\tVin\tPin(mW)\tEff(%)"));
    } else {
        Serial.print(loadName[loadMode]);
        Serial.write('\t');
        Serial.print((int)(idisp_load * 1000));
        Serial.write('\t');
        Serial.print(vdisp_load, 2);
        Serial.write('\t');
        Serial.print((int)(pdisp_load * 1000));
        Serial.write('\t');
        Serial.print((int)(i_meas * 1000));
        Serial.write('\t');
        Serial.print(v_meas, 2);
        Serial.write('\t');
        Serial.print((int)(p_meas * 1000));
        Serial.write('\t');
        Serial.print(eff, 1);
        Serial.println(F("\t"));
    }
}


void interface_get() {
    char *arg = SCmd.next();
    interface_stepsize = 0.0;
    if (arg != NULL) {
        interface_nbSteps = atol(arg);
    } else {
        interface_nbSteps = 2;
    }
    interface_printLoad(true);
}

void interface_sweep() {
    float a, b;
    char *arg = SCmd.next();
    if (arg != NULL) {
        a = (float)atol(arg) / 1000.0;
        arg = SCmd.next();
        if (arg != NULL) {
            b = (float)atol(arg) / 1000.0;
            arg = SCmd.next();
            if (arg != NULL) {

                interface_nbSteps = atol(arg);
                interface_stepsize = (float)(b - a) / ((float)interface_nbSteps);
                interface_nbSteps++;
                getLoadModeFromMenu();
                switch (loadMode) {
                    case CC:
                        inteface_varPt = &i_setV;
                        i_setV.change(a - iset_load);
                        break;
                    case CP:
                        inteface_varPt = &p_setV;
                        p_setV.change(a - pset_load);
                        break;
                    case CR:
                        inteface_varPt = &r_setV;
                        r_setV.change(a - rset_load);
                        break;
                    case BATT:
                        Serial.println(F("Invalid Sweep mode"));
                        return;
                        break;
                }
                Serial.print(F("Starting sweep from "));
                Serial.print(a);
                Serial.print(" to ");
                Serial.print(b);
                Serial.print(" , inc ");
                Serial.println(interface_stepsize);
                interface_printLoad(true);
                load.on(calc_iload());
                return;
            }
        }
    }
    Serial.println(F("Invalid nb of args"));
}

void interface_unrecognized() {
    if (interface_nbSteps) {
        load.off();
        interface_nbSteps = 0;
        Serial.println(F("Emergency stop !"));
    } else {
        Serial.println(F("Help Page"));
        //Serial.println(F("get [x]: returns load info, x times"));
        Serial.println(F("sweep b e s : sweeps mode's parameter from b to e in s steps"));
    }
    Serial.println(F("\r\n"));
}

void interface_poll(void) {
    SCmd.readSerial();
}

void interface_init(void) {
    pinMode(LEDR1_PIN, OUTPUT);
    digitalWrite(LEDR1_PIN, 0);
    SCmd.addCommand("get", interface_get);
    SCmd.addCommand("sweep", interface_sweep);
    SCmd.addDefaultHandler(interface_unrecognized);
}

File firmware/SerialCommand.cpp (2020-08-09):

/*******************************************************************************
    SerialCommand - An Arduino library to tokenize and parse commands received over
    a serial port.
    Copyright (C) 2011-2013 Steven Cogswell  <steven.cogswell@gmail.com>
    http://awtfy.com

    See SerialCommand.h for version history.

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
    You should have received a copy of the GNU Lesser General Public
    License along with this library; if not, write to the Free Software
    Foundation, Inc., 51 Franklin Street, Fifth Floor, Boston, MA  02110-1301  USA
***********************************************************************************/

#include "SerialCommand.h"


#include <string.h>
#ifndef SERIALCOMMAND_HARDWAREONLY
#include <SoftwareSerial.h>
#endif

// Constructor makes sure some things are set.
SerialCommand::SerialCommand()
{
    usingSoftwareSerial = 0;
    strncpy(delim, " ", MAXDELIMETER); // strtok_r needs a null-terminated string
    term = '\r'; // return character, default terminator for commands
    numCommand = 0;  // Number of callback handlers installed
    clearBuffer();
}

#ifndef SERIALCOMMAND_HARDWAREONLY
// Constructor to use a SoftwareSerial object
SerialCommand::SerialCommand(SoftwareSerial &_SoftSer)
{
    usingSoftwareSerial = 1;
    SoftSerial = &_SoftSer;
    strncpy(delim, " ", MAXDELIMETER); // strtok_r needs a null-terminated string
    term = '\r'; // return character, default terminator for commands
    numCommand = 0;  // Number of callback handlers installed
    clearBuffer();
}
#endif


//
// Initialize the command buffer being processed to all null characters
//
void SerialCommand::clearBuffer()
{
    for (int i = 0; i < SERIALCOMMANDBUFFER; i++)
    {
        buffer[i] = '\0';
    }
    bufPos = 0;
}

// Retrieve the next token ("word" or "argument") from the Command buffer.
// returns a NULL if no more tokens exist.
char *SerialCommand::next()
{
    char *nextToken;
    nextToken = strtok_r(NULL, delim, &last);
    return nextToken;
}

// This checks the Serial stream for characters, and assembles them into a buffer.
// When the terminator character (default '\r') is seen, it starts parsing the
// buffer for a prefix command, and calls handlers setup by addCommand() member
void SerialCommand::readSerial()
{
    // If we're using the Hardware port, check it.   Otherwise check the user-created SoftwareSerial Port
#ifdef SERIALCOMMAND_HARDWAREONLY
    while (Serial.available() > 0)
#else
    while ((usingSoftwareSerial == 0 && Serial.available() > 0) || (usingSoftwareSerial == 1 && SoftSerial->available() > 0) )
#endif
    {
        int i;
        boolean matched;
        if (usingSoftwareSerial == 0) {
            // Hardware serial port
            inChar = Serial.read(); // Read single available character, there may be more waiting
        } else {
#ifndef SERIALCOMMAND_HARDWAREONLY
            // SoftwareSerial port
            inChar = SoftSerial->read();   // Read single available character, there may be more waiting
#endif
        }
//#ifdef SERIALCOMMANDDEBUG
        Serial.print(inChar);   // Echo back to serial stream
//#endif
        if (inChar == term) {   // Check for the terminator (default '\r') meaning end of command
#ifdef SERIALCOMMANDDEBUG
            Serial.print("Received: ");
            Serial.println(buffer);
#endif
            bufPos = 0;         // Reset to start of buffer
            token = strtok_r(buffer, delim, &last); // Search for command at start of buffer
            if (token == NULL) return;
            matched = false;
            for (i = 0; i < numCommand; i++) {
#ifdef SERIALCOMMANDDEBUG
                Serial.print("Comparing [");
                Serial.print(token);
                Serial.print("] to [");
                Serial.print(CommandList[i].command);
                Serial.println("]");
#endif
                // Compare the found command against the list of known commands for a match
                if (strncmp(token, CommandList[i].command, SERIALCOMMANDBUFFER) == 0)
                {
#ifdef SERIALCOMMANDDEBUG
                    Serial.print("Matched Command: ");
                    Serial.println(token);
#endif
                    // Execute the stored handler function for the command
                    Serial.print(F("\r\n"));
                    (*CommandList[i].function)();
                    clearBuffer();
                    matched = true;
                    break;
                }
            }
            if (matched == false) {
                (*defaultHandler)();
                clearBuffer();
            }

        }
        if (isprint(inChar))   // Only printable characters into the buffer
        {
            buffer[bufPos++] = inChar; // Put character into buffer
            buffer[bufPos] = '\0'; // Null terminate
            if (bufPos > SERIALCOMMANDBUFFER - 1) bufPos = 0; // wrap buffer around if full
        }
    }
}

// Adds a "command" and a handler function to the list of available commands.
// This is used for matching a found token in the buffer, and gives the pointer
// to the handler function to deal with it.
void SerialCommand::addCommand(const char *command, void (*function)())
{
    if (numCommand < MAXSERIALCOMMANDS) {
#ifdef SERIALCOMMANDDEBUG
        Serial.print(numCommand);
        Serial.print("-");
        Serial.print("Adding command for ");
        Serial.println(command);
#endif

        strncpy(CommandList[numCommand].command, command, SERIALCOMMANDBUFFER);
        CommandList[numCommand].function = function;
        numCommand++;
    } else {
        // In this case, you tried to push more commands into the buffer than it is compiled to hold.
        // Not much we can do since there is no real visible error assertion, we just ignore adding
        // the command
#ifdef SERIALCOMMANDDEBUG
        Serial.println("Too many handlers - recompile changing MAXSERIALCOMMANDS");
#endif
    }
}

// This sets up a handler to be called in the event that the receveived command string
// isn't in the list of things with handlers.
void SerialCommand::addDefaultHandler(void (*function)())
{
    defaultHandler = function;
}

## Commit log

2020-05-29 added project files
    [main.brd, main.sch]
2020-10-21 updated PM to selection of boards
2020-10-22 added board define
2020-10-23 removed debug prints

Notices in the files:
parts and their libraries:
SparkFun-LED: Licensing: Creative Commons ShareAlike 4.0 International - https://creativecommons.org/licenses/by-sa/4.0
